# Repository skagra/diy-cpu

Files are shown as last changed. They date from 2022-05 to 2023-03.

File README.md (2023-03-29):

# DIY CPU

A [meta-project](https://github.com/skagra/diy-cpu-meta) has references to all DIY CPU projects.

This project is a learning exercise in digital electronics, with goals to:

* Design a CPU from the ground up that is op-code compatible with the [6502](https://archive.org/details/mos_microcomputers_programming_manual).
* Implement and validate the design in a digital circuit simulator.
* Implement the design physically, primarily using the [7400](https://en.wikipedia.org/wiki/7400-series_integrated_circuits) series of ICs.

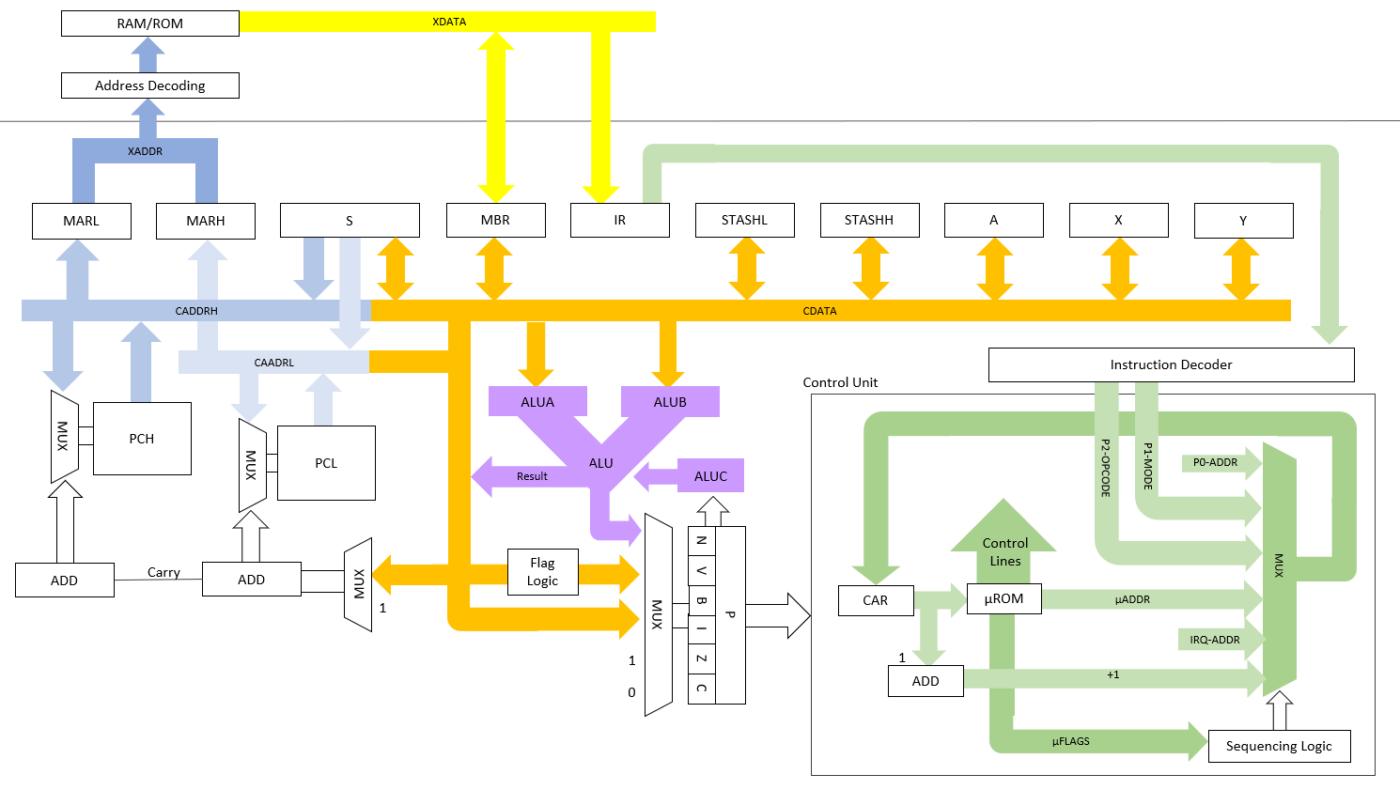
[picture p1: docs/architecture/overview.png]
Overview


* The design is documented [here](docs/architecture/index.md).
* Build/execution instructions are available [here](docs/build-and-run.md).
* Current status is described [here](docs/status.md).

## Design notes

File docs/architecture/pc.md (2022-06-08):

# Program Counter

The *Program Counter* (`PC`) holds the 16 bit address of the current/next machine code instruction.

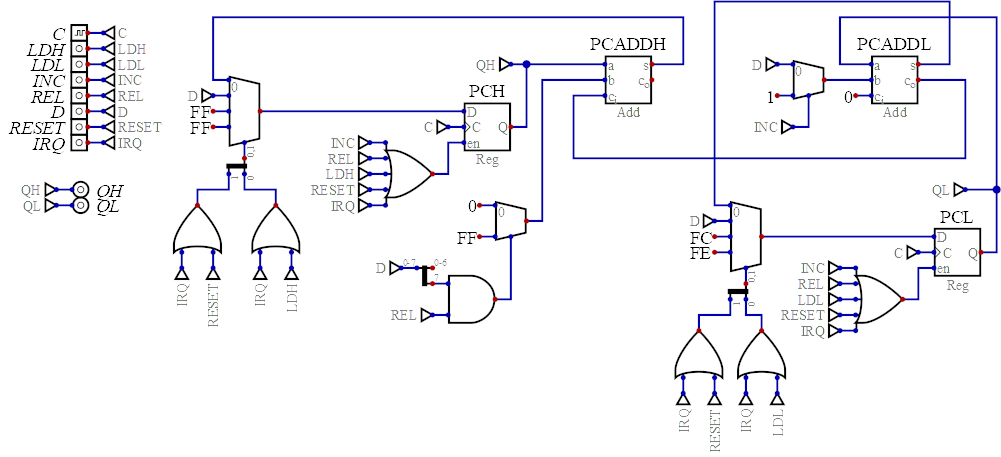
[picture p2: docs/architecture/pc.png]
Program Counter


The circuit allows the PC to be incremented, to be adjusted by a two's complement 8 bit value (to implement relative branches), to load a supplied value (e.g. for absolute jumps) and to load constant values for the interrupt vector (`0xFFFE`) and the reset vector (`0xFFFC`).

# Inputs

* `C` - System clock.
* `LDH` - Set to load the high byte of the `PC` from `D`.
* `LDL` - Set to load the low byte of the `PC` from `D`.
* `INC` - Increment the `PC`.
* `REL` - Adjust the `PC` via `D` as a 8 bit two's compliment value.
* `D` - Incoming data for `LDH`, `LDL` and `REL`.
* `RESET` - Load the reset vector.
* `IRQ` - Load the `IRQ` vector.

# Outputs

* `QH` - `PC` high byte.
* `QL` - `PC` low byte.

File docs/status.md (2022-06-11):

# Status

The CPU is approaching feature completeness in the digital circuit simulator.  It is able to execute most 6502 machine code programs.

The following are still to do:

* BCD mode and `D` flag.
* `B` Flag 

Work has started converting the generic design to 74xx ICs.  So far the ALU and Register have been completed.

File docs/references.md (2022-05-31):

# References

* 6502 Instruction set - good analysis of bit patterns for addressing modes: https://link.springer.com/content/pdf/bbm%3A978-1-349-07360-3%2F1.pdf
* Nice indexed list of opcodes: http://www.6502.org/tutorials/6502opcodes.html
* Table of opcodes with some grouping breakdown https://llx.com/Neil/a2/opcodes.html
* Assembler - DASM https://dasm-assembler.github.io/
* Someone else has done something similar: https://c74project.com/
* Nice summary table of Op Codes https://masswerk.at/6502/6502_instruction_set.html
* 6502 programming manual - https://archive.org/details/mos_microcomputers_programming_manual
* Very nice summary - https://xotmatrix.github.io/6502/6502-instruction-set.html
* Instruction layout - https://www.masswerk.at/6502/6502_instruction_set.html#layout
* Synertek 6502 programming manual - http://archive.6502.org/datasheets/synertek_programming_manual.pdf
* Test rig - www.baltissen.org/zip/rb65-11.zip

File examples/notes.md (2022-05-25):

Many of the examples here, used as test code are taken from http://6502.org/source/.

They have been modified to be compatible with `dasm` and the memory model of the circuit under development.

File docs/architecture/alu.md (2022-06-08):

# ALU

The *Arithmetic Logic Unit* (ALU) provides arithmetic operations, logical operations,  shift and rotate operations to the CPU.

The ALU is divided into three modules:

* *Registers* - Registers that latch input values for the other two modules.
* *ALU-proper* - Arithmetic and logic operations.
* *Shifter* - Shift and rotate operations.

# ALU

The ALU fronts the *ALU-proper* and the *Shifter* with three registers.

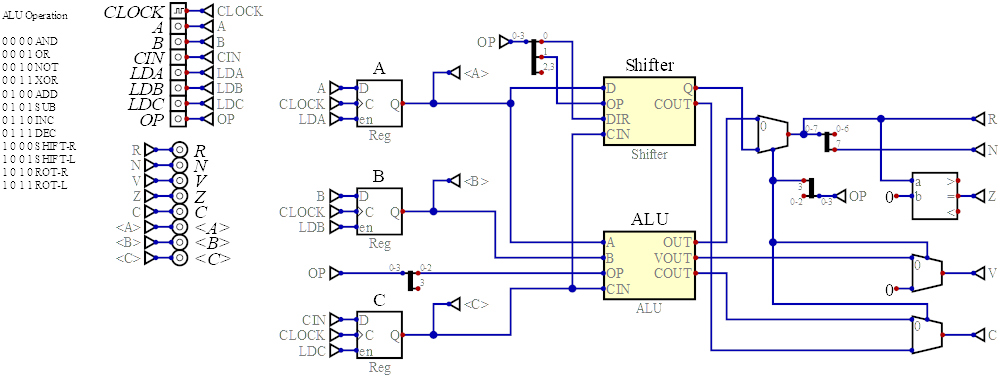
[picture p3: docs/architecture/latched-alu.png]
Latched ALU


The `A` and `B` registers hold the main 8 bit ALU operands and `C` holds an input carry bit.

## Inputs

The latched ALU has the following inputs:

* `CLOCK` - System clock
* `A` - `A` operand
* `B` - `B` operand
* `C` - `C` Carry input
* `LDA` - Set high to load `A`
* `LDB` - Set high to load `B`
* `LDC` - Set high to load `C`
* `OP` - Selects the ALU operation as follows:

    | Value  | Operation      |
    | ------ | -------------- |
    | `0000` | And            |
    | `0001` | Or             |
    | `0010` | Not            |
    | `0011` | Xor            |
    | `0100` | Add            |
    | `0101` | Subtract       |
    | `0110` | Increment A    |
    | `0111` | Decrement A    |
    | `1000` | Shift right A  |
    | `1001` | Shift left A   |
    | `1010` | Rotate right A |
    | `1011` | Rotate left A  |

    The `OP` is processed and passed on to the *ALU-proper* and the *Shifter*, as well as being use to select the appropriate output signal. 

## Outputs

The latched ALU has the following outputs:

* `R` - The result.
* `N` - Set to indicate a negative output (bit 7 set).
* `V` - Set to indicate an arithmetic overflow.
* `Z` - Set to indicate a zero result.
* `C` - Carry out.
* `<A>` - Debugging output giving the value in `A`.
* `<B>` - Debugging output giving the value in `B`. 
* `<C>` - Debugging output giving the value in `C`.

# ALU Proper

The *ALU-Proper* implements arithmetic and logical operations for the CPU.  It is purely combinational logic.

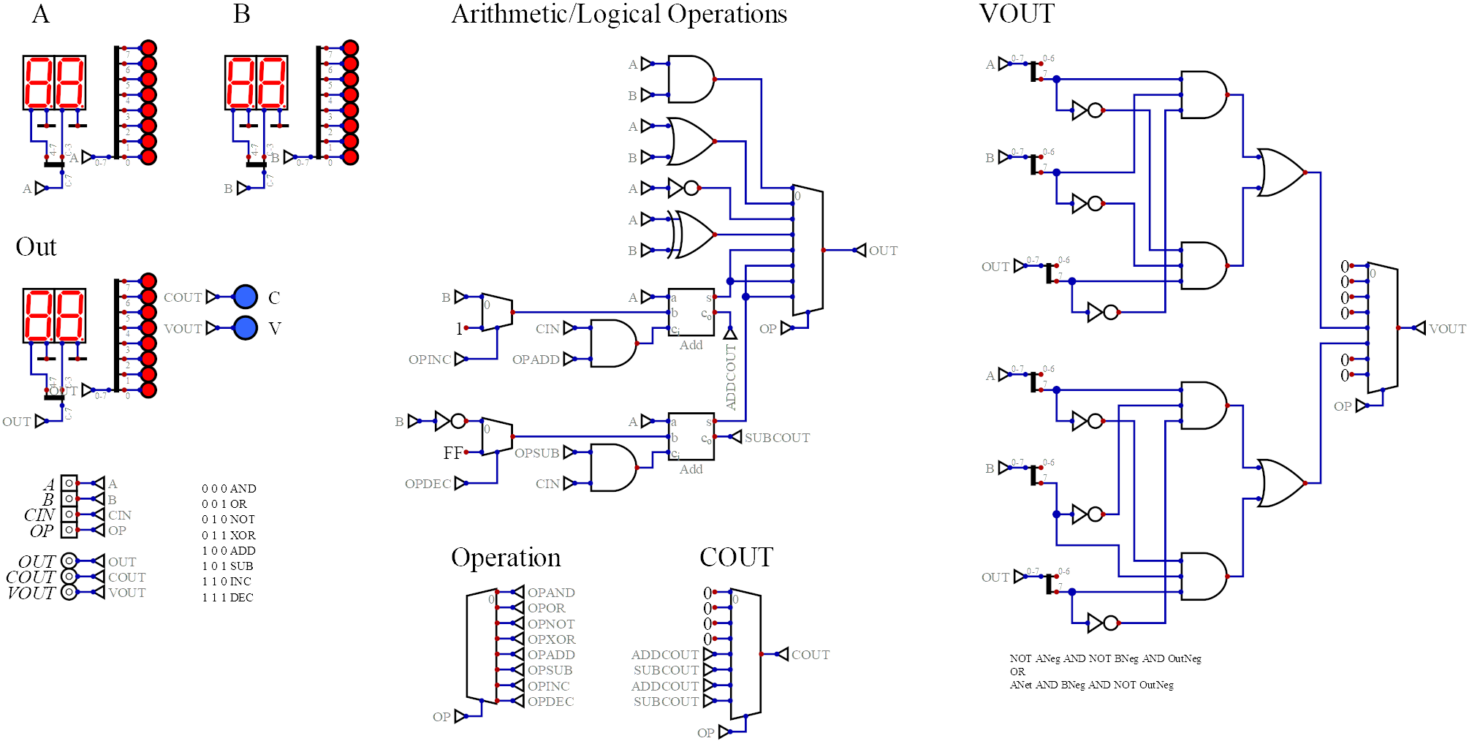
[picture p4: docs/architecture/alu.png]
ALU


## Inputs

* `A` - `A` operand
* `B` - `B` operand
* `C` - `C` Carry input
* `OP` - Selects the ALU operation as follows:

    | Value | Operation     |
    | ----- | --------------|
    | `000` | And           |
    | `001` | Or            |
    | `010` | Not `A`       |
    | `011` | Xor           |
    | `100` | Add           |
    | `101` | Subtract      |
    | `110` | Increment `A` |
    | `111` | Decrement `A` |

## Outputs

* `OUT` - The result.
* `COUT` - Carry out.
* `VOUT` - Set to indicate an arithmetic overflow.

# Shifter

The *Shifter* implements shift and rotate operations for the CPU.  It is purely combinational logic.

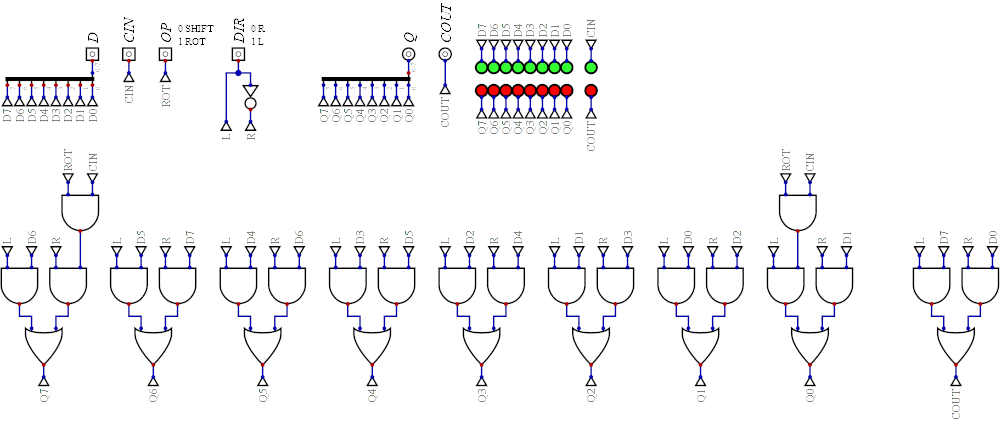
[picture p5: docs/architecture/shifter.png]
Shifter
 

## Inputs

* `D` - Input value.
* `CIN` - Carry in.
* `OP` - Selects the shifter operation as follows:

    | Value | Operation |
    | ----- | --------- |
    | `0`   | Shift     |
    | `1`   | Rotate    |

* `DIR` - Selects the direction of the shift or rotate operation as follows:

    | Value | Operation |
    | ----- | --------- |
    | `0`   | Right     |
    | `1`   | Left      |

## Outputs

* `Q` - Result.
* `COUT` - Carry out.

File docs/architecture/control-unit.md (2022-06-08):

# Control Unit

The control unit governs the operation of the CPU via an array of control lines.   These control lines are driven from *µcode* (microcode) stored in a set of ROMs (`uCode0->uCode5`).  Each µcode instruction gives the high/low value for each control line.  The act of reading a µcode instruction is effectively its execution.

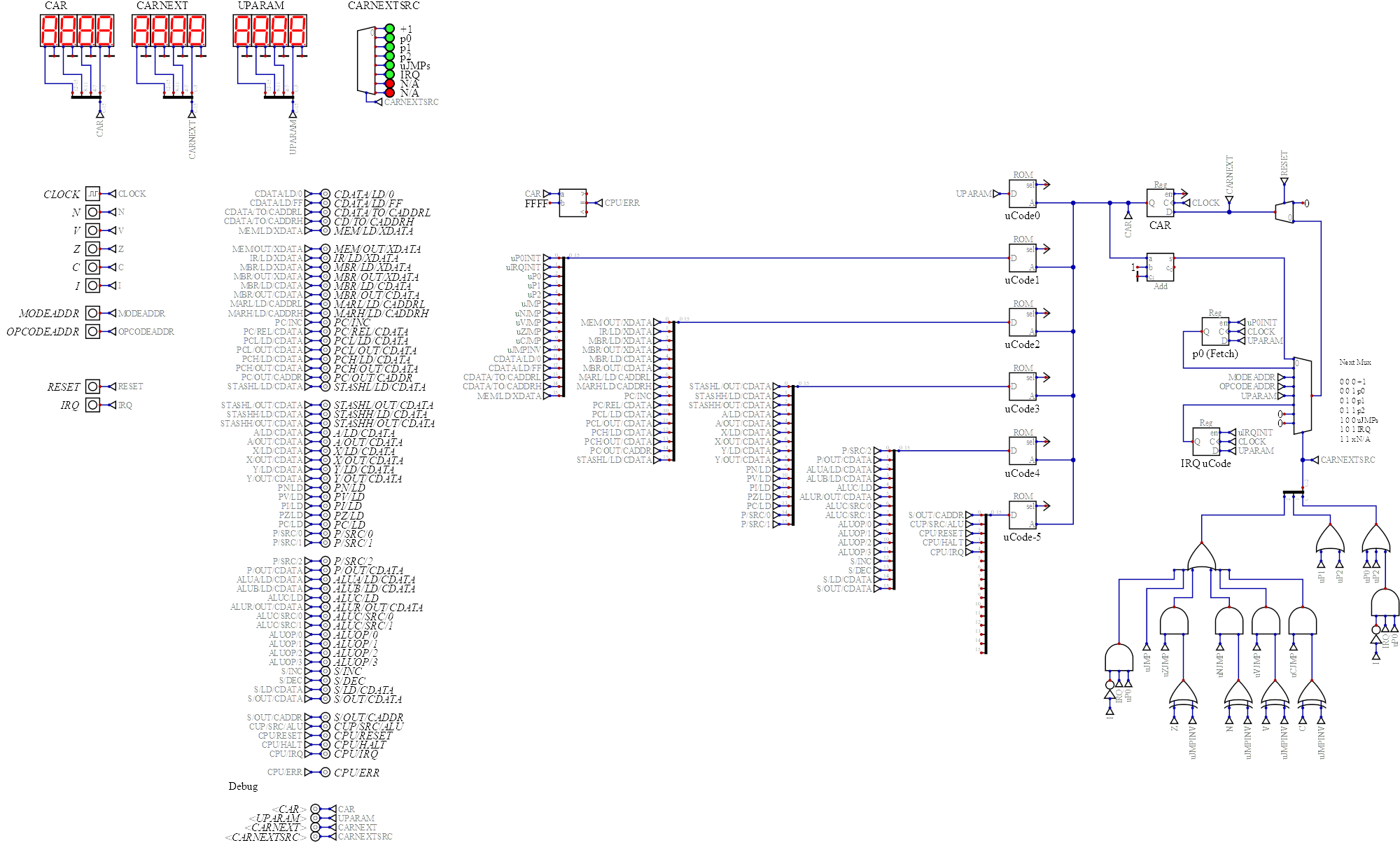
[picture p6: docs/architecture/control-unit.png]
Control Unit


Execution of a machine code instruction is divided into the following µcode phases:

* *p0 Fetch* - The machine code instruction at the address given by the `PC` is fetched from memory into the `IR`.
* *p1 Addressing Mode* - According to the machine code instruction's [addressing mode](addressing-modes.md) (e.g. immediate), µcode is executed to read any arguments from memory concluding with the resolved address of the actual operand in the `MAR`.
* *p2 OpCode* - According to the machine code instruction (e.g. `LDA`), µcode is executed to carry out the appropriate action (e.g. to load a value into `A`). 

The control unit has the following components:

* `CAR` - The *Control Address Register* (`CAR`) contains the address of the current µcode instruction.
* Sequence logic - The sequence logic calculates the address of the next µcode instruction. 

  It consists of a multiplexer which selects from:

  * `CAR + 1` - The address of the subsequent µcode instruction.
  * `p0 (Fetch)` Register - The address of `p0` µcode.
  * `MODEADDR` - The address of the µcode routine associated with the addressing mode of current machine code instruction.
  * `OPCDOEADDR` - The address of the µcode routine associated with the current machine code instruction.
  * `UPARAM` - A optional sixteen bit operand that forms part of each µcode instruction.  Typically it is used to hold the target address of µcode jumps (`uJMP`, `uNJMP`, `uVJMP`, `uZJMP`, `uCJMP`).
  * `IRQ uCode` Register - Contains the address of µcode triggered via an `IRQ`.

  Selection logic picks from the above according to the values of the following bits in the current µcode instruction `IRQ`, `uP0`, `uP1`, `uP2`, `uJMP`, `uNJMP`, `uVJMP`, `uZJMP`, `uCJMP`, `uJMPINV` and the values of the `N`, `V`, `I`, `Z`  and `C` inputs.  These are all described below.

* `p0 (Fetch)` Register - Contains the address of `p0` µcode.   Its value is populated via µcode during CPU initialization.

* `IRQ uCode` Register - Contains the address of µcode to run when an interrupt is signalled.  Its value is populated via µcode during CPU initialization.

* µcode ROMs `uCode0` -> `uCode5`.  The word defining each µcode instruction is divided across the µcode ROMs.  The address of the current µcode instruction is presented to these ROMs to read a µcode instruction.  The act of reading a µcode word sets the control lines it defines.  See below for further details.

* `CAR` Adder - Used to calculate the address of the subsequent µcode instruction (`CAR+1`).

* Error detection - Unknown addressing modes and unknown machine code instructions decode to `0xFFFF`, this causes the control unit to flag an error.

## Microinstruction Format

µcode instructions are 80 bits in length with the following format:

```
0xSSSSSSSSAA
```

The `S` bytes are the values of control signals.  The `A` bytes are a parameter for a µcode operation, most commonly the µcode target address for `uJMP`, `uZJMP`, `uNJMP`, `uVJMP`, `uCJMP` and `uJSR` operations.

µcode instructions are stored in little-endian order when written to the ROM files by the microcode assembler (`microasm`).

```
Natural order                    uROM (little Endian) order
S9 S8 S7 S6 S5 S4 S3 S2 A1 A0 => AO A1 S2 S3 S4 S5 S6 S7 S8 S9 
```

Each `S` bit corresponds either to a control line or to an internal control condition.  A complete µcode instruction is the `or` of these bits together with the optional the `A` parameter bytes.

## Microinstructions & Control Lines

This section describes all implemented the µcode instructions. 

### Control Unit Operations

| Instruction | Meaning |
| --- | --- |
| `uP0INIT` | Initialize the `p0 Fetch` register from the `A` parameter bytes of the µcode instruction. |
| `uIRQINIT`  | Initialize the `IRQ uCode` register from the `A` parameter bytes of the µcode instruction. |
| `uP0` | Jump to `p0` µcode. |
| `uP1` | Jump to `p1` µcode corresponding to the addressing mode of the current machine code instruction. |
| `uP2` | Jump to `p2` µcode corresponding to the the current machine code instruction. |
| `uJMP` | Jump to the µcode at `A`. |
| `uNJMP` | Jump to the µcode at `A` if `N` is set. |
| `uVJMP` | Jump to the µcode at `A` if `V` is set. |
| `uZJMP` | Jump to the µcode at `A` if `Z` is set. |
| `uCJMP` | Jump to the µcode at `A` if `C` is set. |
| `uJMP/INV`  | Invert the logic a `u*JMP` instructions. |

### Constant Values

These constant values used during CPU initialization and reset.

| Instruction | Meaning |
| --- | --- |
| `CDATA/LD/0`  | Set the `CDATA` bus to `0x00`. |
| `CDATA/LD/FF` | Set the `CDATA` bus to `0xFF`. |

### Paths Between Busses

| Instruction | Meaning |
| --- | --- |
| `CDATA/TO/CADDRL` | Open a path from the `CDATA` bus to the `CADDRL` bus. |
| `CDATA/TO/CADDRH` | Open a path from the `CDATA` bus to the `CADDRH` bus. |

### External Data Bus/Memory

| Instruction | Meaning |
| --- | --- |
| `MEM/LD/XDATA`  | Load the value on the `XDATA` bus into memory at the address given on the `XADDR` bus. |
| `MEM/OUT/XDATA` | Write the value in memory at the address on the `XADDR` bus onto the `XDATA` bus. |
| `IR/LD/XDATA` | Load `IR` from the `XDATA` bus. |
| `MBR/LD/XDATA`  | Load `MBR` from the `XDATA` bus. |
| `MBR/OUT/XDATA` | Write `MBR` onto the `XDATA` bus. |

### MBR and the Internal Data Bus

| Instruction | Meaning |
| --- | --- |
| `MBR/LD/CDATA`  | Load `MBR` from the `CDATA` bus. |
| `MBR/OUT/CDATA` | Wite `MBR` onto the `CDATA` bus. |

### MARL and the Internal Address Bus

| Instruction | Meaning |
| --- | --- |
| `MARL/LD/CADDRL` | Load `MARL` from the `CADDRL` bus. |
| `MARH/LD/CADDRH` | Load `MARH` from the `CADDRH` bus. |

### Program Counter

| Instruction | Meaning |
| --- | --- |
| `PC/INC` | Increment `PC` |
| `PC/REL/CDATA`  | Add the signed value on the `CDATA` bus to `PC`. |
| `PCL/LD/CDATA`  | Load `PCL` from the `CDATA` bus. |
| `PCL/OUT/CDATA` | Write `PCL` to the `CDATA` bus. |
| `PCH/LD/CDATA`  | Load `PCH` from the `CDATA` bus. |
| `PCH/OUT/CDATA` | Write `PCH` to the `CDATA` bus. |
| `PC/OUT/CADDR`  | Write `PC` to the `CADDR` bus. |

### General Purpose Registers

| Instruction | Meaning |
| --- | --- |
| `STASHL/LD/CDATA`  | Load `STASHL` from the `CDATA` bus. |
| `STASHL/OUT/CDATA` | Write `STASHL` to the `CDATA` bus.  |
| `STASHH/LD/CDATA`  | Load `STASHH` from the `CDATA` bus. |
| `STASHH/OUT/CDATA` | Write `STASHH` to the `CDATA` bus.  |
| `A/LD/CDATA` | Load `A` from the `CDATA` bus. |
| `A/OUT/CDATA` | Write `A` to the `CDATA` bus. |
| `X/LD/CDATA` | Load `X` from the `CDATA` bus. |
| `X/OUT/CDATA` | Write `X` to the `CDATA` bus. |
| `Y/LD/CDATA` | Load `Y` from the `CDATA` bus. |
| `Y/OUT/CDATA` | Write `Y` to the `CDATA` bus. |

### Status (P) Flags

| Instruction | Meaning |
| --- | --- |
| `PN/LD` | Load the `N` flag. |
| `PV/LD` | Load the `V` flag. |
| `PV/LD` | Load the `B` flag. |
| `PI/LD` | Load the `I` flag. |
| `PZ/LD` | Load the `Z` flag. |
| `PC/LD` | Load the `C` flag. |

The source of the value loaded into `P` flags is controlled by:

```
P/SRC/0          
P/SRC/1                
P/SRC/2   
```

As follows:

| P/SRC/* | Source |
| --- | --- |
| `000` | Reset. |
| `001` | Set. |
| `010` | `ALU` out. |
| `011` | Flags processed from `CDATA`. |
| `100` | Raw `CDATA`. |
| `1xx` | N/A. |

| Instruction | Meaning |
| --- | --- |
| `P/OUT/CDATA` | Write `P` to the `CDATA` bus. |

### ALU

| Instruction | Meaning |
| --- | --- |
| `ALUA/LD/CDATA`  | Load `ALUA` from the `CDATA` bus. |
| `ALUB/LD/CDATA`  | Load `ALUB` from the `CDATA` bus. |
| `ALUC/LD` | Load `ALUC` from the `CDATA` bus. |
| `ALUR/OUT/CDATA` | Write the ALU result to the `CDATA` bus. |

The source of the value loaded into `ALUC` is controlled by:

```
ALUC/SRC/0       
ALUC/SRC/1       
```

As follows:

| ALUC/SRC/* | Meaning |
| --- | --- |
| `00` | Reset. |
| `01` | Set. |
| `10` | `P` flag (`C`). |
| `11` | N/A. |

The operation carried out by the `ALU` is controlled by:

```
ALUOP/0         
ALUOP/1          
ALUOP/2         
ALUOP/3  
```

As follows:

| ALU/OP/* | Meaning |
| --- | --- |
| `0000` | And |
| `0001` | Or |
| `0010` | Not |
| `0011` | Xor |
| `0100` | Add |
| `0101` | Sub |
| `0110` | Inc |
| `0111` | Dec |
| `1000` | Shift right  |
| `1001` | Shift left |
| `1010` | Rotate right |
| `1011` | Rotate left  |
        
### Stack Pointer

| Instruction | Meaning |
| --- | --- |
| `S/INC` | Increment `S`. |
| `S/DEC` | Decrement `S`. |
| `S/LD/CDATA`  | Load `S` from the `CDATA` bus. |
| `S/OUT/CDATA` | Write `S` (LSB) to the `CDATA` bus. |
| `S/OUT/CADDR` | Write `S` to the `CADDR` bus (high byte is always `0x01`). |

### Control Unit

| Instruction | Meaning |
| --- | --- |
| `CUP/SRC/ALU` | Source of `P` flags for the control unit. |

Where:

| Value | Meaning |
| ----- | --- |
| `0` | Read flags from `P`. |
| `1` | Read flags from the `ALU` output. |

### State

| Instruction | Meaning |
| --- | --- |
| `CPU/RESET` | Reset to the CPU. `PC` will be set to the reset vector. |
| `CPU/HALT`  | Halt the CPU |
| `CPU/IRQ` | Flag a `IRQ` to the CPU - `PC` will be set to the `IRQ/BRK` vector. |

## Inputs

| Name | Function |
| --- | --- |
| `CLOCK` | System clock. |
| `N` | `N` flag. |
| `V` | `V` flag. |
| `I` | `I` flag. |
| `Z` | `Z` flag. |
| `C` | `C` flag. |
| `MODEADDR` | Address of the µcode that implements the addressing mode of the current machine code instruction. |
| `OPCODEADDR` | Address of the µcode that implements the current machine code instruction. |
| `RESET` | A request to reset the CPU. |
| `IRQ` | An interrupt request. |

## Outputs

In addition to an output for each control line bit corresponding to a µcode instruction, the control unit has the following outputs.

| Name | Function |
| --- | --- |
| `CPU/ERR` | A error condition has been detected. |
| `<CAR>` | Debugging output giving the value of `CAR` |
| `<UPARAM>` | Debugging output giving the value the `A` bytes parameter of the current µcode instruction. |
| `<CARNEXT>` | Debugging output giving the address of the next µcode instruction. |
| `<CARNEXTSRC>` | Debugging output giving the source of the address of the next µcode instruction. |

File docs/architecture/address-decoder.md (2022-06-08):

# Address Decoder

The *Address Decoder* allows one of four memory banks to be enabled based on a target memory address.

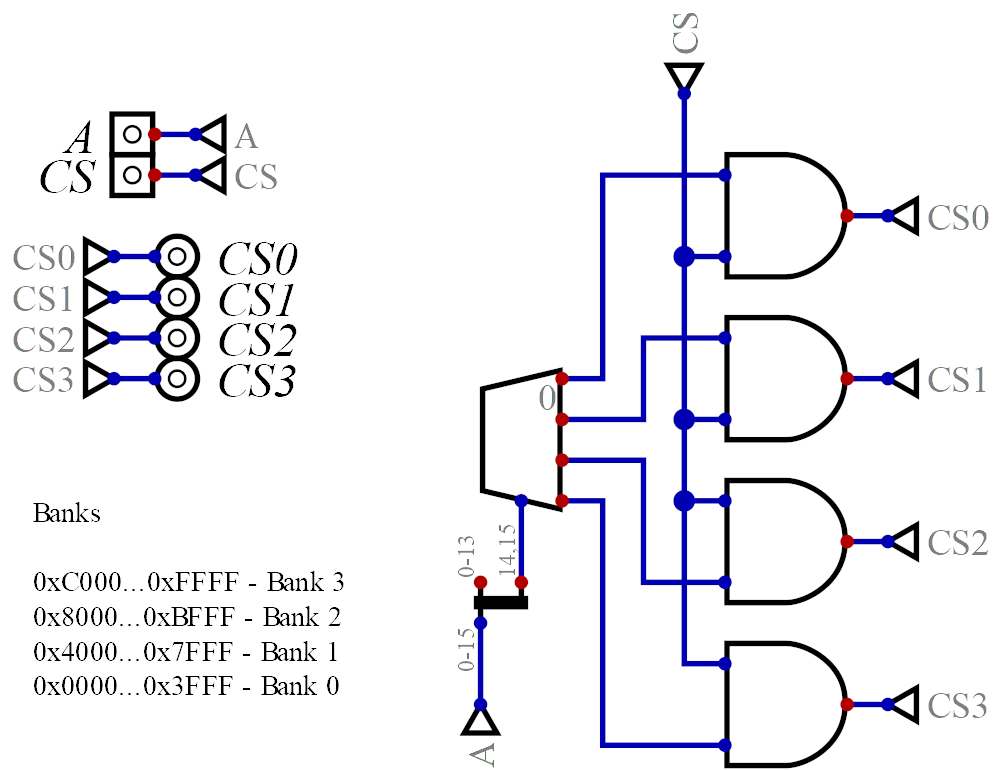
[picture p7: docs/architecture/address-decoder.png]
Address Decoder


| Range | Bank |
| --- | ---- |
| `0xC000...0xFFFF` | 3 |
| `0x8000...0xBFFF` | 2 |
| `0x4000...0x7FFF` | 1 |
| `0x0000...0x3FFF` | 0 |

Bank selection is based on the 2 most significant bits of the address.

# Inputs

* `A` - Address.
* `CS` - Chip select, set high to enable.

# Outputs

* `CS3` - Address is in the range for bank 3.
* `CS2` - Address is in the range for bank 2.
* `CS1` - Address is in the range for bank 1.
* `CS0` - Address is in the range for bank 0.

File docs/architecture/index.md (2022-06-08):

# Overview

The following diagram shows a high level block view of the CPU together with some external components.

Overview

* *RAM/ROM* - Program code.
* *Address Decoding* - The [address decoder](address-decoder.md) maps memory addresses onto banks of memory.
* `XADDR` and `XDATA` Buses - The *eXternal ADDRess bus* (`XADDR`) and the *eXternal DATA bus* (`XDATA`) connect the CPU with memory (RAM/ROM) and memory mapped I/O.
* `MARH/MARL` and `MBR` Registers - The *Memory ADDRess High/Low* registers (`MARH/MARL`) target a memory location and the *Memory Buffer Register* (`MBR`) stores data read from/to be written to, memory.
* `IR` *Instruction Register* - The *Instruction Register* (`IR`) stores the currently executing machine code instruction read from memory.
* `CADDRH/CADDRL` Registers - The *Cpu ADDRess High/Low* buses (`CADDRH/CADDRL`) allow memory addresses calculated within the CPU to be transferred to `MARH/MARL`.                                 
* `PCH/PCL` Registers - The [Program Counter High/Low](pc.md) registers (`PCH/PCL`) hold the memory address of the currently executing machine code instruction. 
* `CDATA` Bus - The *Cpu DATA bus* (`CDATA`) allows data transfer within the CPU.  
* `S` *Stack Register* - The *Stack register* (`S`) points to the next free stack location in memory. 
* `P` *Status Register* - The *status register* (`P`) holds CPU status flags, for example the `C` flag which signals carry from a proceeding `ALU` addition. 
* `STASHH`/`STASHL` Internal Registers - Used to store temporary values when processing machine code instructions.
* `A`/`X`/`Y` General Purpose Registers - General purpose registers available to the programmer.
* `ALU` *[Arithmetic Logic Unit](alu.md)* - Arithmetic, logical, shift and rotate operations.
* *Instruction Decoder* - The [instruction decoder](instruction-decoder.md) maps machine code instructions onto µcode routines in the [control unit](control-unit.md).
* *Control Unit* - The [control unit](control-unit.md) orchestrates to operation of the CPU via a set of control lines.

The following shows a more detailed architectural diagram:

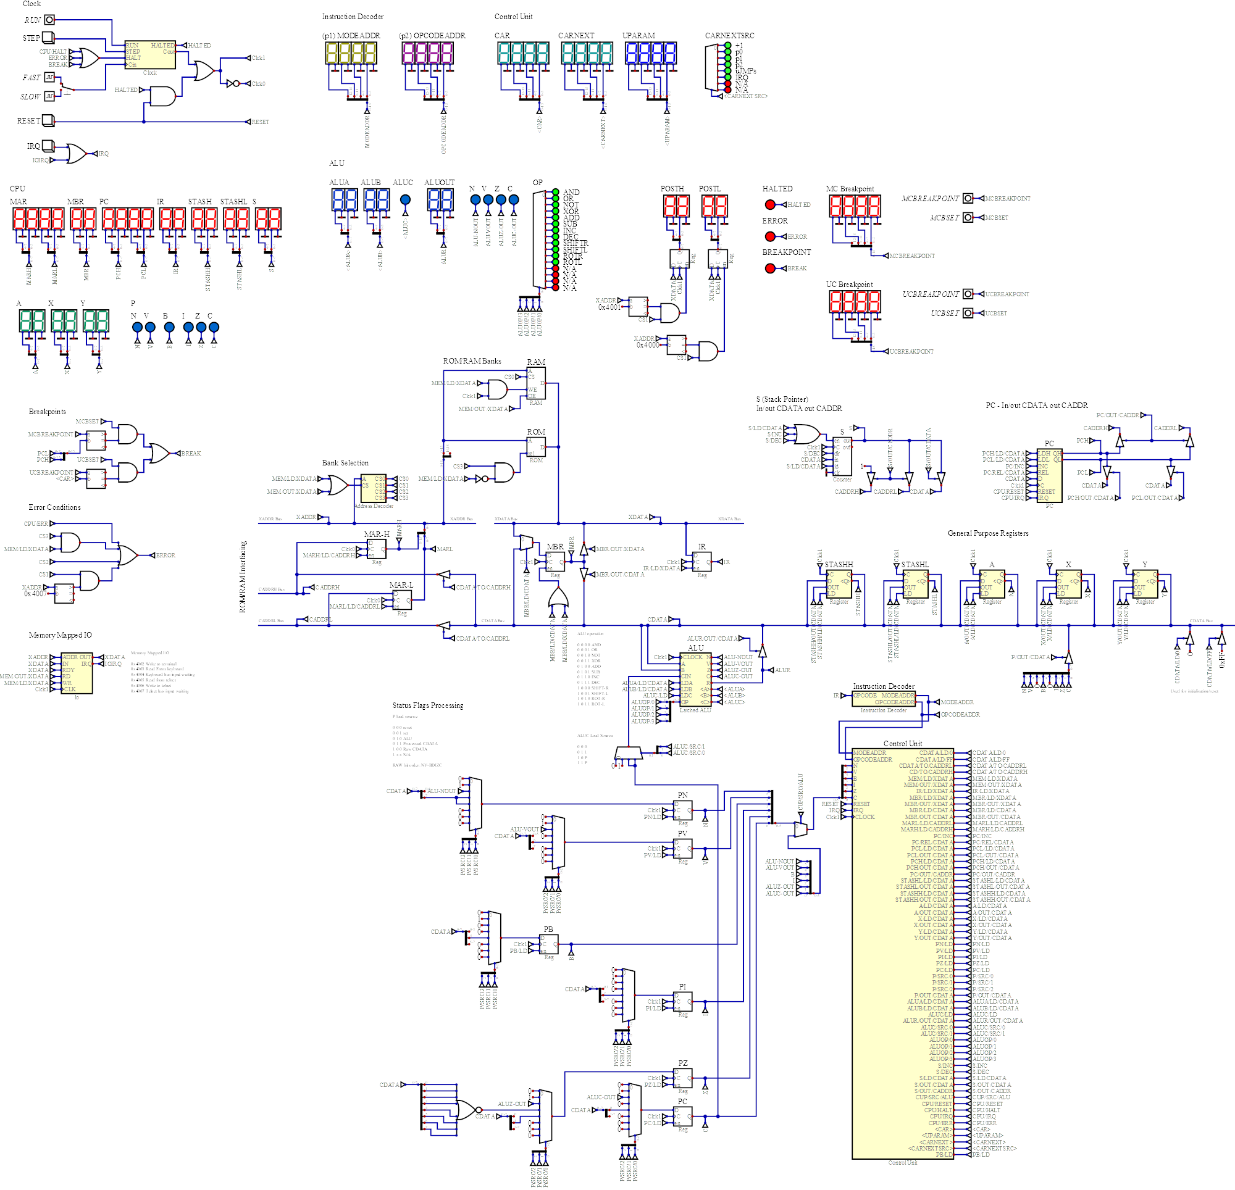
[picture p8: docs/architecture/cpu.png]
CPU


Essentially this diagram is the same as the high level block version.   The major additions are the inclusion of control lines driven from the control unit, tri-state buffers to govern bus access and some logic to deal with status flags.

Each of sub-modules of the CPU is described in detail here:

* [ALU](alu.md) - The *Arithmetic/Logic Unit*.
* [Control Unit](control-unit.md) - The *Control Unit*.
* [Address Decoder](address-decoder.md) - The *Address Decoder*.
* [Instruction Decoder](instruction-decoder.md) - The *Instruction Decoder*.
* [Program Counter](pc.md) - The *Program Counter*.
* [Register](register.md) - Stores 8 bit values.

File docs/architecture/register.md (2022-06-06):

# Register

The register stores a single 8 bit value and has a tri-state output.

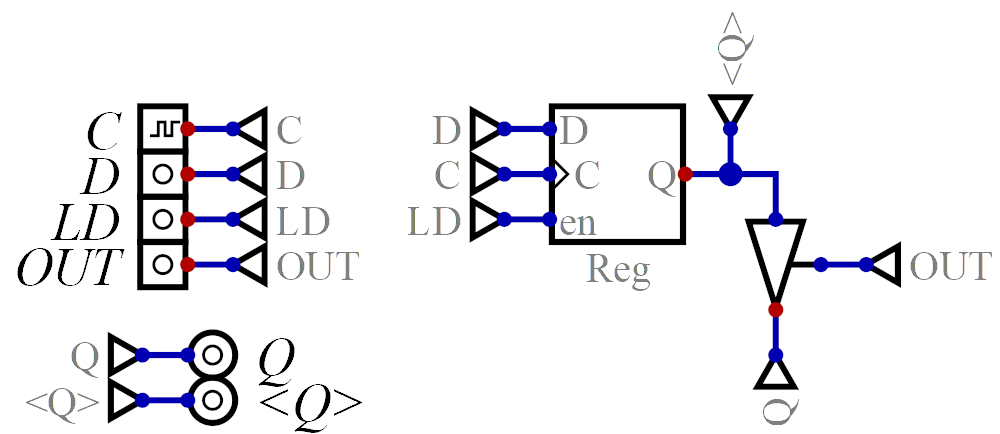
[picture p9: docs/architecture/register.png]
Register


# Inputs

* `C` - System clock.  Value is stored on the rising clock edge.
* `D` - Data value to store.
* `LD` - Set high to load a value.
* `OUT` - Set to output value.

# Outputs

* `Q` - Output value when `OUT` is high.
* `<Q>` - Debugging output always giving current value (prior to the tri-state buffer).

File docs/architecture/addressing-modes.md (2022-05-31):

# Addressing Modes

| Mode | Example | Description |
| --- | --- | --- |
| Accumulator  | `ASL A` | Implicitly targets the accumulator |
| Absolute | `ADC $4400` | Argument gives the address of the operand. |
| Absolute, X  | `ADC $4400,X` | Argument is added to X (with carry) to give the two byte address of the operand. |
| Absolute, Y  | `ADC $4400,Y` | Argument is added to Y (with carry) to give the two byte address of the operand. |
| Immediate | `ADC #$44` | Argument is the operand. |
| Implied | `TSX` | No operand |
| Indirect | `JMP ($5597)` | Argument gives the address of a two byte value used as the target of a JMP operation. **Note** that in a 6502 the calculation of the address of the second indirected byte is done without carry!  So the operation will not give the expected result where the argument refers to the last byte in a page. Used only for JMP. |
| X, Indirect  | `ADC ($44,X)` | The one byte argument is added to X to give a zero-page address.  The two byte value at that address points to the operand.  Addition wraps to zero-page. |
| Indirect, Y  | `ADC ($44),Y` | The argument points to a two byte zero page value which is retrieved and added to Y to give address of the operand. |
| Relative | `BPL $50` | The operand is an 8 bit signed offset from the PC. |
| Zero page | `ADC $44` | The argument is the zero-page address of the operand |
| Zero page, X | `ADC $44,X` | The zero page argument is added to X to give the zero page address of the operand.  Addition wraps to zero page. |
| Zero page, Y | `STA $00,Y` | The zero page argument is added to Y to give the zero page address of the operand.  Addition wraps to zero page.

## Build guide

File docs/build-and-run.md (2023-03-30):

# Overview

The project has the following structure:

* `asminclude` - Machine code include files.
* `digital/generic` - The CPU as models for the `Digital` circuit simulator.
* `docs` - Documentation.
* `examples` - Example machine code used to exercise the CPU.
* `microasm` - The μcode assembler.
* `os` - Machine code for an interrupt handler and definition of `IRQ` and reset vectors.
* `tests` - Machine code to test the μcode implementation of each machine code instruction.
* `ucode` - The μcode used by the [control unit](architecture/control-unit.md) to orchestrate the operation of the CPU and the definition the decoder ROMs used in the [instruction decoder](architecture/address-decoder.md).

# Build and Run

The build process requires:

* Compilation of the μcode assembler (`microasm`).
* Use of `microasm` to assemble μcode and decoder ROMs.
* Assembly of some of system machine code.
* Assemble of the *user* machine code program to execute.   
* Configuration of the digital circuit simulator to use the the above. 

1. Run the `all` task in Visual Studio Code.  This will:

   * Compile the microcode assembler (`microasm`).

   * Assemble all machine code:

      * `examples` - Example machine code programs to run on the CPU.
      * `os` - The *operating system*.  Actually just an interrupt handler and settings for the `IRQ` vector and reset vector.
      * `tests` - Machine code tests to check all machine code instructions are correctly implemented.
      
1. Run `microasm` to build the μcode ROM images and decoder ROM images:

   * `uROM-[0-5].bin` - μcode routines executed by the *control unit* to orchestrate the operation of the CPU.
   * `mModeDecoder.bin` - Addressing mode decoder ROM.
   * `mOpDecoder.bin` - Machine instruction decoder ROM.
   
   If you run via `Ctrl f5` in Visual Studio Code then the correct parameters will be supplied.  
   
   Otherwise you need to supply the the directory containing the μcode definitions and an output directory.  
   
   For example, from the root directory of the repo:

      `dotnet run --project microasm ucode <output-dir>`

1. Configure the `digital` circuit simulator to use the built μcode and decoder ROMs.

   * Run `digital` and open `digital/generic/CPU.dig`.

   * Configure the decoder ROMs
      * Right click on the *Instruction Decoder* and select *Open Circuit*.
         * Right click on the *p1 (Mode)* ROM and select the *Advanced* tab.
         * Set the *File* value to the location of the `uCode/bin/mModeDecoder.bin` built above.
         * Click `OK` to close the dialog.
         * Right click on the *p2 (OpCode)* ROM and select the *Advanced* tab.
         * Set the *File* value to the location of the `uCode/bin/mOpDecoder.bin` built above.
         * Click `OK` to close the dialog.
         * Save and close the *Instruction Decoder* window.

      * Right click on the *Control Unit* and select *Open Circuit*.
         * One by one, right click on each of the `uCode[0-5]` ROM.
         * Select the *Advanced* tab.
         * Set the *File* value to the appropriate `uCode/bin/uROM-[0-5].bin` built above.
         * Click `OK` to close the dialog.
         * When all 6 are configured save and close the *Control Unit* window.
      
1. Configure the `digital` circuit simulator to run chosen machine code.

   * Configure the operating system (just a simple interrupt handler and `IRQ` and reset vectors):
      * Right click on *ROM*.
      * Select the *Advanced* tab.
      * Set the *File* value to the the os file `os/bin/os.bin`.
      * Click `OK` to close the dialog.

   * Configure the machine code program to run.   The machine code built above from the `examples` directory contains sample machine code programs.  To configure the chosen program:
      * Select *Circuit specific settings* from the *Edit* menu.
      * Select the *Advanced* tab.
      * Set the *File* value to the required machine code e.g. `examples/bin/RAM.bin`.
       * Click `OK` to close the dialog.

1. And finally run the simulation.

   * Select *Start of Simulation* from the *Simulation* menu.

   * The simulation will start with the CPU halted.  Click the `RUN` button (top left hand corner of the circuit) the start the CPU.

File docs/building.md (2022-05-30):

# Building

The following tools are needed to build/run DIY CPU:

* Digital Circuit Emulation: [Digital](https://github.com/hneemann/Digital)
* 6502 Assembler: [DASM](https://dasm-assembler.github.io/)
* Microasm: [DotNet](https://dotnet.microsoft.com/en-us/download)

While not required, the [Visual Studio Code](https://code.visualstudio.com/) is used for the project so all build targets etc. should work out of the box.

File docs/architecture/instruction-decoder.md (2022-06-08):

# Instruction Decoder

The instruction decoder processes machine code instructions to locate their associated µcode implementations.

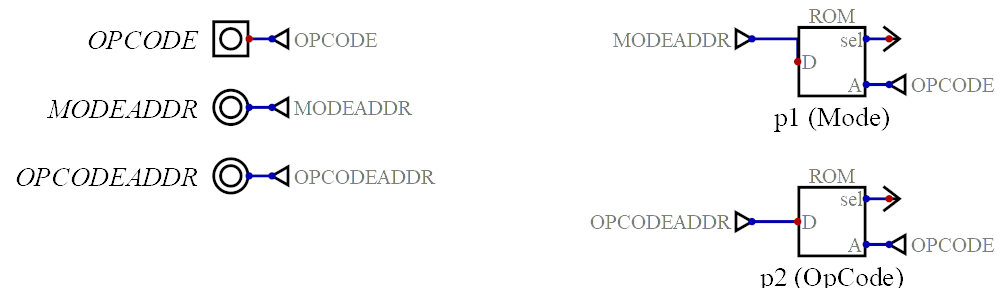
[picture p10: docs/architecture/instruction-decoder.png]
Instruction Decoder


A machine code instruction is presented as a memory address to a decoder ROM.  The decoder ROM is programmed such that the data at this memory location contains the address of the associated µcode routine in the [Control Unit](control-unit.md).  

There are two decoder ROMs:

* `p1 (Mode)` ROM - The `p1 (Mode)` ROM locates µcode that implements the [addressing mode](addressing-modes.md) of the presented machine code instruction.

* `p2 (Opcode)` ROM - The `p2 (Opcode)` ROM locates µcode that implements the presented machine code instruction.

# Inputs

* `OPCODE` - The machine code instruction to decode.

# Outputs

* `MODEADDR` - The address of the µcode implementing the machine code instruction's addressing mode.

* `OPCODEADDR` - The address of the µcode implementing the the machine code instruction.

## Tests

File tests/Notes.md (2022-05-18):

Imported from www.baltissen.org/zip/rb65-11.zip then modified.

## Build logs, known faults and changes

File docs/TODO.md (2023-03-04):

# TO DO

# Next Steps

1. Label
1. Tidy circuit
1. Upload and test new MC
1. Make uCode jumps relative
1. Build memory decoder
1. Build memory mapped I/O
1. Build PC
1. Add RAM
1. Build controller

# For Current Version

* The current reset mechanism relies on a clock pulse - consider instead using the the reset line on the CAR register (pulling low momentarily via a RC circuit).
* Update build instructions to reflect inclusion of simplified version and use of `Makefiles`.   
* Make microcode assembler work with different ROM sizes without code edits.

# For Later Version

* Revisit size of uCode ROM
* ALU
  * Consider design of ALU flag handling, can this be simplified?
  * Do we need a latch on the output of the ALU?
  * Consider direct connection between A and ALUA - this might cut cycles for most ALU operations by 1
  * Check the subtraction logic in the PC ADD circuit
  * Take a very careful look at ADC, SBC, CMPs and setting of C and V flags
* Clock
  * Investigate using multiple phases of clocks to reduce execution cycles
* Microasm
  * Consider generating HTML as asm output optionally then we can have mouse overs to ID flags and to link to definitions
  * Have microasm account for where word size does not fit exactly with uROMs
  * Complete validation routines
  * Improve log output implementation in microasm - its all over the code base at the moment with multiple hard coded numbers
* Write up current design
  * Architecture
  * Explanation of all control signals
  * etc.
* Microcode  
  * Check order of pushing bytes of addresses onto stack for JSR (and later BRK)
  * BRK is this a one byte or two byte opcode?
  * Add/review setting of P flags for all existing operations
* Finish integrating test rig
* IRQ implementation still needs work
* B flag
* BDC implement (and D flag)

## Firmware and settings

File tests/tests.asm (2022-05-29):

            PROCESSOR 6502

; TTL-6502 PROGRAM

Z10		= $10
Z18		= $18
Z19		= $19
Z20		= $20
Z30		= $30
Z50		= $50
ZF0		= $F0

A0400	= $1B00
A0420	= $1B20
A0450	= $1B50
A04AA	= $1BAA

;**  LED DISPLAY ON 1541 BOARD
   	INCDIR "../asminclude"
    INCLUDE "io.h"

POSTCODE = POSTL

    ORG $0
    DS $200 
	ORG $200
  
RESET
;		SEI
;		NOP


;***  1541 PART  ***
;		CLD

;**  CHECK IF JMP WORKS FINE
		LDA	#0
		STA	POSTCODE

		JMP	L999

;* SHOULD NOT BE EXECUTED AT ALL
		NOP
		SEC
L000C
		BCS	L000C
		
		NOP
L000
		JMP	M372
		
		NOP
L000A
		CLC
		LDA	#0
		RTS
		
		NOP

		
;**  TEST BRANCHES WITH ALL FLAGS SET
L005
		LDA	#1
		STA	POSTCODE

		LDX	#$FF
		TXS

		LDA	#$FF
		PHA
		PLP			; SET ALL FLAGS

;!! REMARK: IF AN ERROR OCCURS, DON'T FORGET THAT ONE OF THE ABOVE INSTRUCTIONS
;           COULD HAVE BEEN THE CAUSE INSTEAD.
L001
		BCC	L001
L002
		BNE	L002
L003
		BVC	L003
L004
		BPL	L004

		BMI	L006		; MUST BRANCH, ELSE ERROR
L004A
		JMP	L004A		; ERROR, ->
L006
		BEQ	L007		; MUST BRANCH, ELSE ERROR
L006A
		JMP	L006A		; ERROR, ->
L007
		BVS	L008		; MUST BRANCH, ELSE ERROR
L007A
		JMP	L007A		; ERROR, ->
L008
		BCS	L010		; MUST BRANCH, ELSE ERROR
L008A
		JMP	L008A		; ERROR, ->

;**  TEST BRANCHES WITH ALL FLAGS RESET
L010
		LDA	#2
		STA	POSTCODE

		LDA	#0
		PHA
		PLP			; RESET ALL FLAGS
L011
		BCS	L011
L012
		BEQ	L012
L013
		BVS	L013
L014
		BMI	L014

		BCC	L015		; MUST BRANCH, ELSE ERROR
L014A
		JMP	L014A		; ERROR, ->
L015
		BNE	L016		; MUST BRANCH, ELSE ERROR
L015A
		JMP	L015A		; ERROR, ->
L016
		BVC	L017		; MUST BRANCH, ELSE ERROR
L016A
		JMP	L016A		; ERROR, ->
L017
		BPL	L020		; MUST BRANCH, ELSE ERROR
L017A
		JMP	L017A		; ERROR, ->


;**  TEST SEC, CLC AND CLV
L020
		LDA	#3
		STA	POSTCODE
L020C
		BEQ	L020C		; MUST SKIP, ELSE ERROR

		BNE	L020E		; MUST BRANCH, ELSE ERROR
L020D
		JMP	L020D
L020E
		SEC
L020A
		BCC	L020A		; ERROR, ->

		BCS	L021		; MUST BRANCH, ELSE ERROR
L020B
		JMP	L020B		; ERROR, ->

L021
		CLC
L021A
		BCS	L021A		; ERROR, ->

		BCC	L022		; MUST BRANCH, ELSE ERROR
L021B
		JMP	L021B		; ERROR, ->

L022
		CLV
L022A
		BVS	L022A		; ERROR, ->

		BVC	L030		; MUST BRANCH, ELSE ERROR
L022B
		JMP	L022B		; ERROR, ->


;**  TEST LDA/X/Y #N, STA/X/Y $XX/$XXXX
L030
		LDA	#4
		STA	POSTCODE

		LDA	#0
		
; THIS JUST CHECKS THE ALU, NOT A
L031
		BNE	L031		; ERROR, ->
L032
		BMI	L032		; ERROR, ->

; TEST THE CONTENT OF A
		CMP	#0
L031A
		BNE	L031A		; ERROR, ->

		STA	Z10
		STA	A0400

		LDA	#$80

; THIS JUST CHECKS THE ALU, NOT A
L033
		BEQ	L033		; ERROR, ->
L034
		BPL	L034		; ERROR, ->

; TEST THE CONTENT OF A
		CMP	#$80
L035
		BNE	L035		; ERROR, ->

		STA	Z10+1
		STA	A0400+1

		LDX	#0
		CPX	#0
L036
		BNE	L036		; ERROR, ->

		STX	Z10+2
		STX	A0400+2

;**  TEST BRANCH AROUND PAGE BORDER  ==>
		CLC
		BCC	L40M

L40B
		SEC
		BCS	L40Z
		
		NOP
		NOP

L40M
		BCC	L40B
						
L40Z
; <==


		LDX	#$80
		CPX	#$80
L037
		BNE	L037		; ERROR, ->

		STX	Z10+3
		STX	A0400+3

		LDY	#0
		CPY	#0
L038
		BNE	L038		; ERROR, ->

		STY	Z10+4
		STY	A0400+4

		LDY	#$80
		CPY	#$80
L039
		BNE	L039		; ERROR, ->

		STY	Z10+5
		STY	A0400+5


;**  TEST LDA/X/Y $XX
		LDA	#5
		STA	POSTCODE

		LDA	Z10
		CMP	#0
L039E
		BNE	L039E		; ERROR, ->

		LDA	#0
		LDA	Z10+1
		CMP	#$80
L039G
		BNE	L039G		; ERROR, ->


		LDX	#5
		LDX	Z10
		CPX	#0
L039I
		BNE	L039I		; ERROR, ->


		LDX	#0
		LDX	Z10+1
		CPX	#$80
L039K
		BNE	L039K		; ERROR, ->


		LDY	#5
		LDY	Z10
		CPY	#0
L039M
		BNE	L039M		; ERROR, ->


		LDY	#0
		LDY	Z10+1
		CPY	#$80
L039O
		BNE	L039O		; ERROR, ->


;**  TEST LDA/X/Y $XXXX
		LDA	#6
		STA	POSTCODE

		LDA	A0400
		CMP	#0
L041
		BNE	L041		; ERROR, ->


		LDA	A0400+1
		CMP	#$80
L043
		BNE	L043		; ERROR, ->


		LDX	A0400
		CPX	#0
L044
		BNE	L044		; ERROR, ->


		LDX	A0400+1
		CPX	#$80
L044C
		BNE	L044C		; ERROR, ->


		LDY	A0400
		CPY	#0
L044E
		BNE	L044E		; ERROR, ->

		LDY	A0400+1
		CPY	#$80
L044G
		BNE	L044G		; ERROR, ->


;**  TEST CMP/CPX/CPY
;* REGISTER = VALUE
		LDX	#0
		LDY	#0
		LDA	#7
		STA	POSTCODE
		STA	Z10
		STA	A0400
		CMP	#7
L051
		BNE	L051		; ERROR, ->
L052
		BCC	L052		; ERROR, ->
L053
		BMI	L053		; ERROR, ->


		CMP	Z10
L051A
		BNE	L051A		; ERROR, ->
L052A
		BCC	L052A		; ERROR, ->
L053A
		BMI	L053A		; ERROR, ->


		CMP	A0400
L051B
		BNE	L051B		; ERROR, ->
L052B
		BCC	L052B		; ERROR, ->
L053B
		BMI	L053B		; ERROR, ->


		LDX	#7
		CPX	#7
L051C
		BNE	L051C		; ERROR, ->
L052C
		BCC	L052C		; ERROR, ->
L053C
		BMI	L053C		; ERROR, ->


		CPX	Z10
L051D
		BNE	L051D		; ERROR, ->
L052D
		BCC	L052D		; ERROR, ->
L053D
		BMI	L053D		; ERROR, ->


		CPX	A0400
L051E
		BNE	L051E		; ERROR, ->
L052E
		BCC	L052E		; ERROR, ->
L053E
		BMI	L053E		; ERROR, ->


		LDY	#7
		CPY	#7
L051F
		BNE	L051F		; ERROR, ->
L052F
		BCC	L052F		; ERROR, ->
L053F
		BMI	L053F		; ERROR, ->


		CPY	Z10
L051G
		BNE	L051G		; ERROR, ->
L052G
		BCC	L052G		; ERROR, ->
L053G
		BMI	L053G		; ERROR, ->


		CPY	A0400
L051H
		BNE	L051H		; ERROR, ->
L052H
		BCC	L052H		; ERROR, ->
L053H
		BMI	L053H		; ERROR, ->

;* REGISTER > MEMORY
		LDA	#8
		STA	POSTCODE

		CMP	#7
L061
		BEQ	L061		; ERROR, ->
L062
		BCC	L062		; ERROR, ->
L063
		BMI	L063		; ERROR, ->


		CMP	Z10
L061A
		BEQ	L061A		; ERROR, ->
L062A
		BCC	L062A		; ERROR, ->
L063A
		BMI	L063A		; ERROR, ->


		CMP	A0400
L061B
		BEQ	L061B		; ERROR, ->
L062B
		BCC	L062B		; ERROR, ->
L063B
		BMI	L063B		; ERROR, ->


		LDX	#8
		CPX	#7
L061C
		BEQ	L061C		; ERROR, ->
L062C
		BCC	L062C		; ERROR, ->
L063C
		BMI	L063C		; ERROR, ->


		CPX	Z10
L061D
		BEQ	L061D		; ERROR, ->
L062D
		BCC	L062D		; ERROR, ->
L063D
		BMI	L063D		; ERROR, ->


		CPX	A0400
L061E
		BEQ	L061E		; ERROR, ->
L062E
		BCC	L062E		; ERROR, ->
L063E
		BMI	L063E		; ERROR, ->


		LDY	#8
		CPY	#7
L061F
		BEQ	L061F		; ERROR, ->
L062F
		BCC	L062F		; ERROR, ->
L063F
		BMI	L063F		; ERROR, ->


		CPY	Z10
L061G
		BEQ	L061G		; ERROR, ->
L062G
		BCC	L062G		; ERROR, ->
L063G
		BMI	L063G		; ERROR, ->


		CPY	A0400
L061H
		BEQ	L061H		; ERROR, ->
L062H
		BCC	L062H		; ERROR, ->
L063H
		BMI	L063H		; ERROR, ->


;* REGISTER < MEMORY
		LDA	#5
		CMP	#7
L071
		BEQ	L071		; ERROR, ->
L072
		BCS	L072		; ERROR, ->
L073
		BPL	L073		; ERROR, ->


		CMP	Z10
L071A
		BEQ	L071A		; ERROR, ->
L072A
		BCS	L072A		; ERROR, ->
L073A
		BPL	L073A		; ERROR, ->


		LDX	#5
		CPX	#7
L071B
		BEQ	L071B		; ERROR, ->
L072B
		BCS	L072B		; ERROR, ->
L073B
		BPL	L073B		; ERROR, ->


		CPX	Z10
L071C
		BEQ	L071C		; ERROR, ->
L072C
		BCS	L072C		; ERROR, ->
L073C
		BPL	L073C		; ERROR, ->


		CPX	A0400
L071D
		BEQ	L071D		; ERROR, ->
L072D
		BCS	L072D		; ERROR, ->
L073D
		BPL	L073D		; ERROR, ->


		LDY	#5
		CPY	#7
L071E
		BEQ	L071E		; ERROR, ->
L072E
		BCS	L072E		; ERROR, ->
L073E
		BPL	L073E		; ERROR, ->


		CPY	Z10
L071F
		BEQ	L071F		; ERROR, ->
L072F
		BCS	L072F		; ERROR, ->
L073F
		BPL	L073F		; ERROR, ->


		CPY	A0400
L071G
		BEQ	L071G		; ERROR, ->
L072G
		BCS	L072G		; ERROR, ->
L073G
		BPL	L073G		; ERROR, ->
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

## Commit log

2022-05-05 Experminented with having memory in sub-circuit, can get the bi-direction bus to connect properly
2022-05-09 Added another couple of ops
2022-05-18 Updated clock circuit to make reset more reliable
2022-05-20 Added more ops and fixed bug in PC circuit when adding -ive offset
2022-05-25 Fixed ALU circuit bug that was causing square.asm to fail
2022-05-31 To force case changes
2022-05-31 Trying to change case of name
2022-05-31 Fixing case of filename
2022-06-04 Updated ALU docs and polished circuit presentation!
2022-09-07 Towards a full 74HCxx implementation of simplified CPU
    [alu board.fzz, carry board.fzz]
2022-09-07 Added pulldown resistors
2022-09-10 Progress on 74xx migrated design
    [register.fzz]
2022-10-19 Multiple updates!
    [alu board power to z.fzz, alu board power.fzz, alu board.fzz]
2022-11-19 Updated board code
2022-12-04 Added alt circuit to reduce quantity or ROMS
2023-03-28 Major move around done
    [alu board power to z.fzz, alu board power.fzz, alu board.fzz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]
